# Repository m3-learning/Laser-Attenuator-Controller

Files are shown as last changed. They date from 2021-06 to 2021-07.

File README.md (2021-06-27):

# Laser-Attenuator-Controller

Open source laser attenuator controller

Created by: The M3 Learning Group

All designs and code by: Ryan Forelli

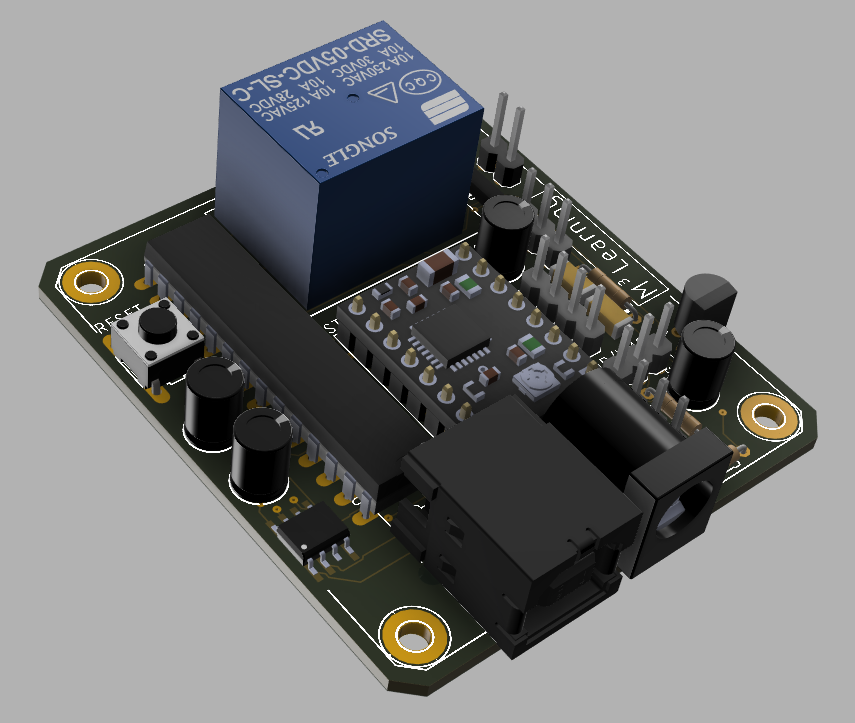
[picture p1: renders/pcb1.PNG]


## Components needed for PCB assembly
-   1x Custom PCB
-   1x A4988 stepper motor drivers
-   1x ATmega328P AVR microcontroller
-   1x Male & female pin header set
-   1x through hole pushbutton
-   1x 16 MHz crystal oscillator
-   2x 22pF ceramic capacitors
-   1x 10uF electrolytic capacitor
-   1x 100uF electrolytic capacitor
-   2x 100nF capacitors
-   3x 10k through-hole resistor
-   1x Assorted solid-core jumper wires
-   1x [Standoffs][0] (optional)
-   1x Custom back plate (optional)
-   1x [USB to TTL Adapter][2]
-   1x PN2222 transistor
-   1x 1N400X series diode
-   1x 5V SRD-05VDC-SL-C relay
-   1x CH330N USB to serial chip (optional if using USB to TTL Adapter)
-   1x 5.5x2.1 DC power port
-   1x USB type B female port

Our open source PCB and firmware can be used to control an attenuator controller to adjust the power output of a laser for applications such as pulsed laser deposition. The program attenuator_control.exe can be used to communicate with the ATmega328p microcontroller to control the attenuator. The LabVIEW and C++ source code is available in the repository.

## Installation Notes
-   Supply PCB with 5V from USB to TTL Adapter.
-   Supply stepper motor controller and relay with 24V.

<!-- ## Usage Instructions
-   Power PLD Controller module
-   Open LabVIEW pldsyscontrol.exe and run Virtual Instrument (VI)
-   Select COM port
-   Home raster motor (does not home to a specific target)
-   Select target and begin use -->

[0]: https://www.amazon.com/Csdtylh-Male-Female-Standoff-Stainless-Assortment/dp/B06Y5TJXY1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
[1]: https://www.amazon.com/gp/product/B074M15FS1/ref=ppx_yo_dt_b_asin_title_o02_s00?ie=UTF8&psc=1
[2]: https://www.amazon.com/DSD-TECH-SH-U09C2-Debugging-Programming/dp/B07TXVRQ7V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

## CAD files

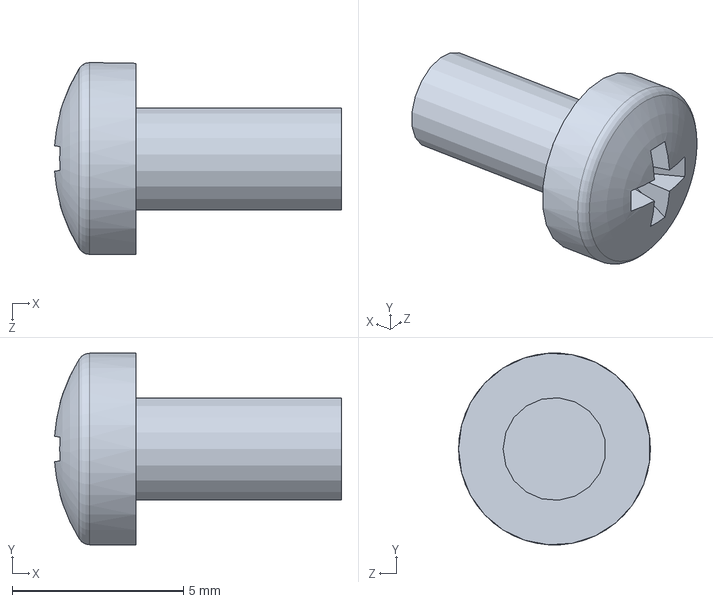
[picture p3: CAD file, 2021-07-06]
3d_models/PCB_shield/Tornillo acero M3x6mm.SLDPRT
8.37 x 5.59 x 5.60 mm

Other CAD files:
3d_models/OldVersions/side plate.0002.ipt
3d_models/PCB_shield/Assembly1.iam
3d_models/PCB_shield/OldVersions/Assembly1.0005.iam
3d_models/PCB_shield/OldVersions/Tornillo acero M3x6mm.0001.ipt
3d_models/PCB_shield/OldVersions/shield.0004.ipt
3d_models/PCB_shield/Tornillo acero M3x6mm.ipt
3d_models/PCB_shield/shield.ipt
3d_models/laser_pcb.ipt
3d_models/side plate.ipt

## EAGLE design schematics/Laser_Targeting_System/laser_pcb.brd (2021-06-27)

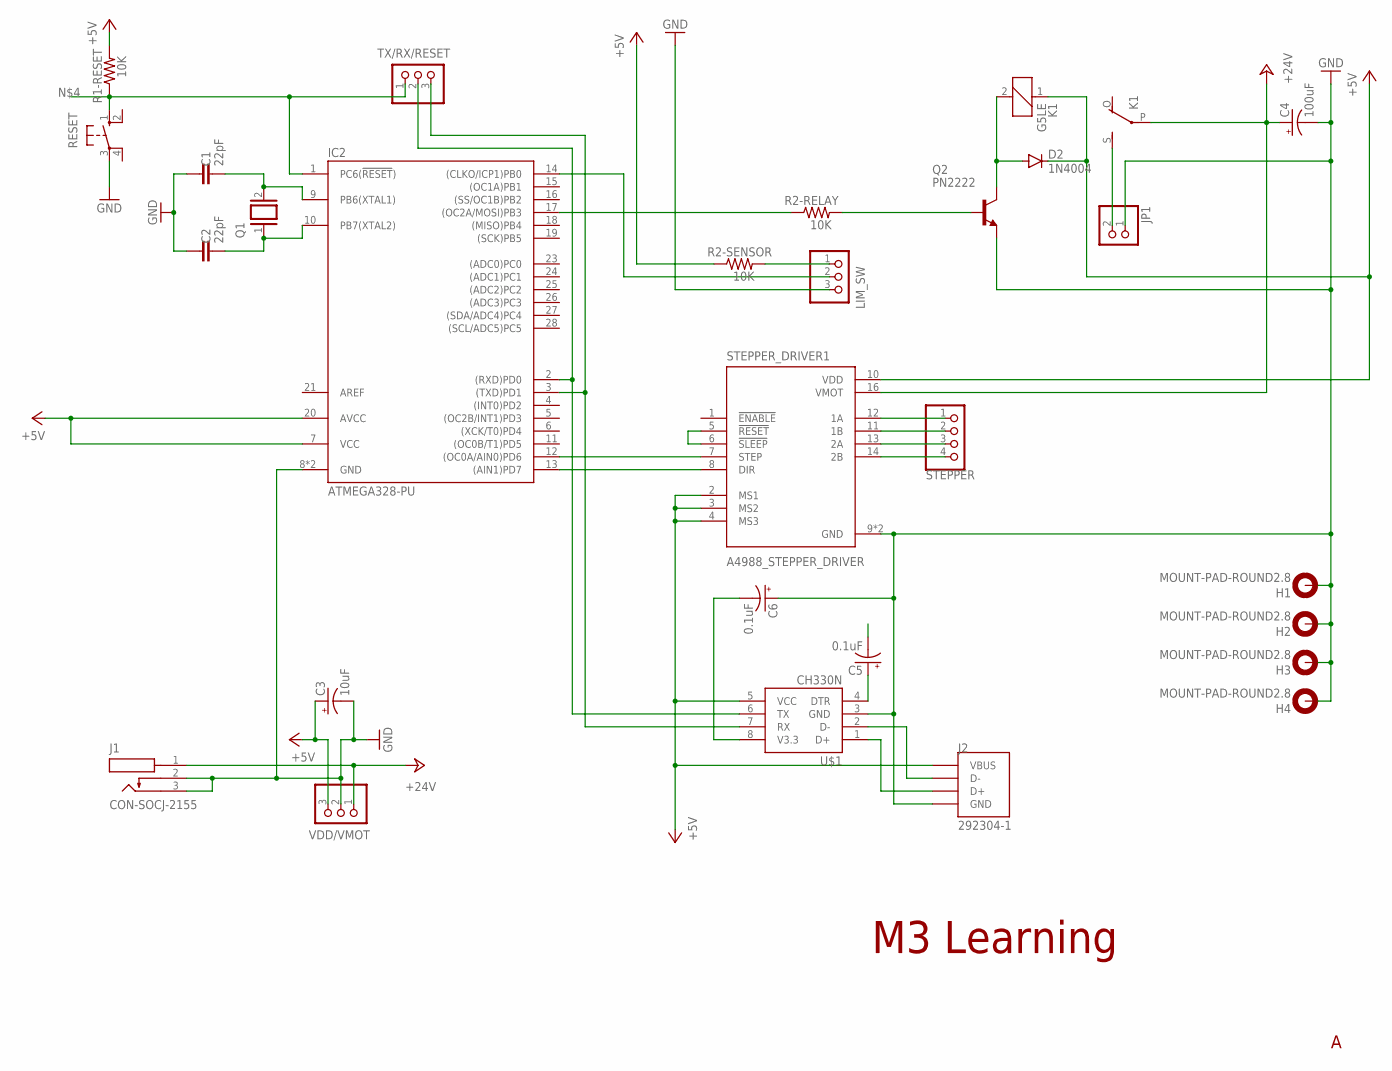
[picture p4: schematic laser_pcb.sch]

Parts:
C1, C2: 22pF; CAP-PTH-2.54
C3: 10uF; CPOL-RADIAL-2.5MM-5MM
C4: 100uF; CPOL-RADIAL-2.5MM-5MM
C5, C6: 0.1uF; CPOL-RADIAL-2.5MM-5MM
D2: 1N4004; DO41-10
H1, H2, H3, H4: MOUNT-PAD-ROUND2.8; 2,8-PAD
IC2: ATMEGA328-PU; DIL28
J1: CON-SOCJ-2155; GRAVITECH_CON-SOCJ-2155
J2: 292304-1; TE_292304-1
JP1: PINHD-1X2; 1X02
K1: G5LE
LIM_SW: PINHD-1X3; 1X03
Q1: XTAL/S; QS
Q2: PN2222; TO92
R1-RESET, R2-RELAY, R2-SENSOR: 10K; 0204/7
RESET: 10-XX; B3F-10XX
STEPPER: PINHD-1X4; 1X04
STEPPER_DRIVER1: A4988_STEPPER_DRIVER; MODULE_A4988_STEPPER_MOTOR_DRIVER_CARRIER
TX/RX/RESET: PINHD-1X3; 1X03
U$1: CH330N; SOIC8
VDD/VMOT: PINHD-1X3; 1X03

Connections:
+5V: C3.1 (+), D2.C, IC2.7 (VCC), IC2.20 (AVCC), J2.1 (VBUS), K1.1, R1-RESET.2, R2-SENSOR.1, STEPPER_DRIVER1.2 (MS1), STEPPER_DRIVER1.3 (MS2), STEPPER_DRIVER1.4 (MS3), STEPPER_DRIVER1.10 (VDD), U$1.5 (VCC), VDD/VMOT.3
+24V: C4.1 (+), J1.1, K1.P, STEPPER_DRIVER1.16 (VMOT), VDD/VMOT.1
GND: C1.1, C2.1, C3.2 (-), C4.2 (-), C6.1 (+), H1.B2,8, H2.B2,8, H3.B2,8, H4.B2,8, IC2.8 (GND), IC2.22 (GND), J1.2, J1.3, J2.4 (GND), JP1.1, LIM_SW.3, Q2.1 (E), RESET.3, STEPPER_DRIVER1.9 (GND), STEPPER_DRIVER1.15 (GND), U$1.3 (GND), VDD/VMOT.2
unnamed: C1.2, IC2.9 (PB6(XTAL1)), Q1.2
unnamed: C2.2, IC2.10 (PB7(XTAL2)), Q1.1
unnamed: C5.2 (-), IC2.1 (PC6(!RESET!)), R1-RESET.1, RESET.1 (S), TX/RX/RESET.1
unnamed: STEPPER_DRIVER1.5 (!RESET), STEPPER_DRIVER1.6 (!SLEEP)
unnamed: IC2.13 ((AIN1)PD7), STEPPER_DRIVER1.8 (DIR)
unnamed: IC2.12 ((OC0A/AIN0)PD6), STEPPER_DRIVER1.7 (STEP)
unnamed: STEPPER.1, STEPPER_DRIVER1.12 (1A)
unnamed: STEPPER.2, STEPPER_DRIVER1.11 (1B)
unnamed: STEPPER.3, STEPPER_DRIVER1.13 (2A)
unnamed: STEPPER.4, STEPPER_DRIVER1.14 (2B)
unnamed: LIM_SW.1, R2-SENSOR.2
unnamed: Q2.2 (B), R2-RELAY.2
unnamed: IC2.14 ((CLKO/ICP1)PB0), LIM_SW.2
unnamed: JP1.2, K1.S
unnamed: D2.A, K1.2, Q2.3 (C)
unnamed: IC2.17 ((OC2A/MOSI)PB3), R2-RELAY.1
unnamed: J2.2 (D-), U$1.2 (D-)
unnamed: J2.3 (D+), U$1.1 (D+)
unnamed: C5.1 (+), U$1.4 (DTR)
unnamed: C6.2 (-), U$1.8 (V3.3)
unnamed: IC2.2 ((RXD)PD0), TX/RX/RESET.2, U$1.6 (TX)
unnamed: IC2.3 ((TXD)PD1), TX/RX/RESET.3, U$1.7 (RX)

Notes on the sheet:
M3 Learning

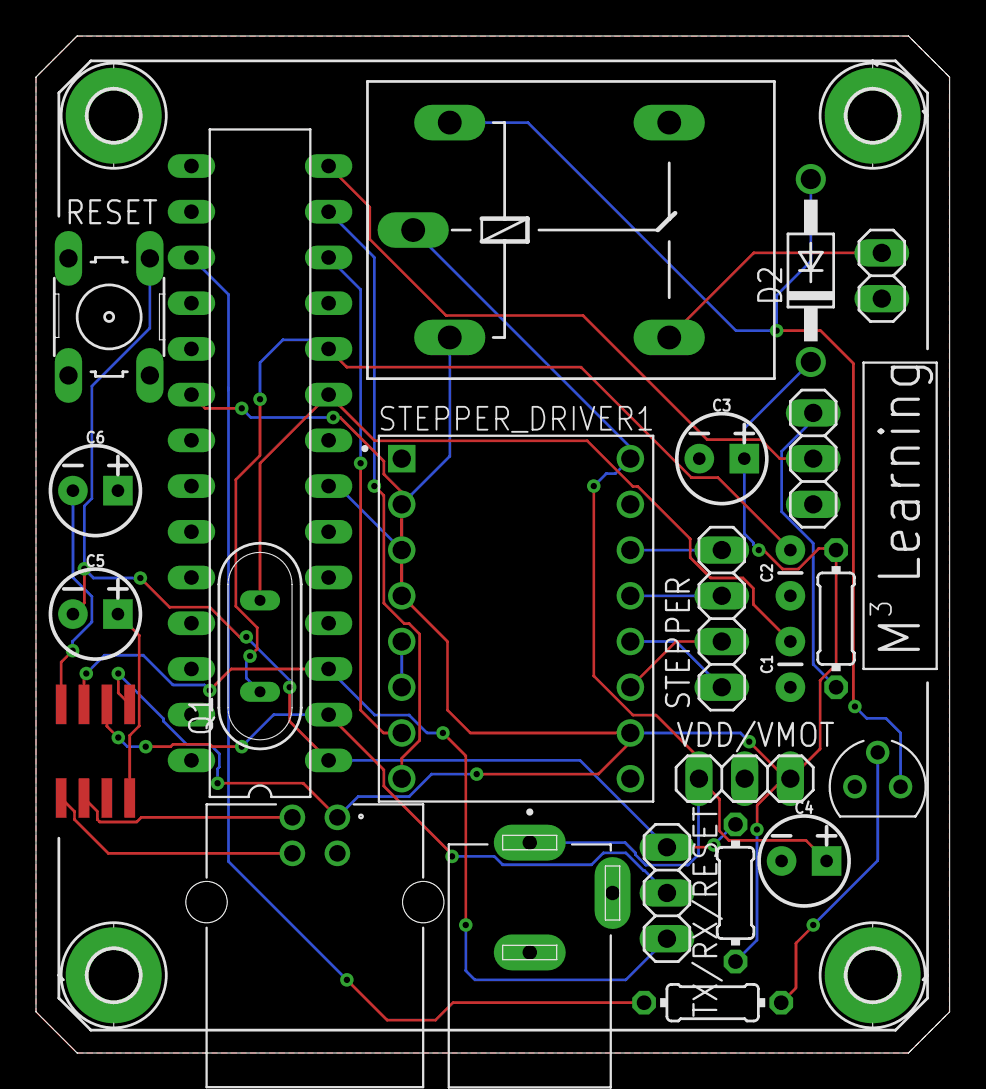
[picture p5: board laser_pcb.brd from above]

Board: 2 copper layers, 50.8 x 56.5 mm, 28 parts (0 on the bottom side), 25 nets.

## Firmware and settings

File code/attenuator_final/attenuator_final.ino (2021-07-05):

#include <Arduino.h>
#include <math.h>

/*
 * By: Ryan Forelli
 * M3 Learning group
 * Current setup has ~3538 steps per degree (with MS 1, 2, and 3 set high)
 * Default speed is 5 deg/sec
*/

unsigned long steps_rotate_per_rev = 1273808;              //Steps required for one revolution
unsigned long max_angle = 90;                              //Maximum allowed angle for attenuator
int steps_per_deg = 3538;                                  //Steps per degree
unsigned long steps_max_angle = max_angle * steps_per_deg; //Steps to maximum angle

float curr_angle = 0;                                      //Current angle
float dest_angle = -1;                                     //Destination angle
float angle_rotate = -1;                                   //Degrees to rotate to reach destination angle
unsigned long steps_rotate;                                //Steps to rotate to reach destination
unsigned long calibration_counter = 0;

char command;                                              //Command from user

unsigned long delay_micros;                                //Delay in microseconds to achieve desired angular velocity

//Macros
#define CW HIGH                                            //Clockwise
#define CCW LOW                                            //Counter Clockwise
#define DIR_PIN 7                                          //Dir pin on A4988
#define STEP_PIN 6                                         //Step pin on A4988
#define LASER_BLOCK 11                                     //Rotary solenoid pin
#define HOME_SWITCH 8                                      //Limit switch pin
#define MIN_SPEED 1                                        //Minimum speed in deg/sec
#define MAX_SPEED 8                                        //Maximum speed in deg/sec
#define STEP                      \
    digitalWrite(STEP_PIN, HIGH); \
    digitalWrite(STEP_PIN, LOW);  \
    delayMicroseconds(delay_micros)
#define setRotationSpeed(new_rotation_speed) ((1 / (double)(steps_per_deg * new_rotation_speed)) * 1000000) //Set rotation speed
#define setDirection(dir) (digitalWrite(DIR_PIN, dir))                                                      //Set direction
#define BLOCK_LASER digitalWrite(LASER_BLOCK, LOW)                                                          //Block laser path
#define CLEAR_LASER digitalWrite(LASER_BLOCK, HIGH)                                                         //Clear laser path

void setup(){
    Serial.begin(9600);

    //Set inputs and outputs
    pinMode(LASER_BLOCK, OUTPUT);
    pinMode(HOME_SWITCH, INPUT);
    pinMode(DIR_PIN, OUTPUT);
    pinMode(STEP_PIN, OUTPUT);
    delay_micros = setRotationSpeed(5);
}

void loop(){
    //Check for available characters to read from serial port
    if (Serial.available() > 0){ Serial.readBytes(&command, 1); }

    switch (command){
        case ',':{ //Rotate to the desired angle
            dest_angle = Serial.parseFloat(SKIP_NONE, ',');
            if ((dest_angle != curr_angle) && (dest_angle <= max_angle) && (dest_angle >= 0)){
                angle_rotate = abs(curr_angle - dest_angle);
                setDirection(((curr_angle - dest_angle) > 0));
                curr_angle = dest_angle;
                //steps_rotate = map(angle_rotate, 0, max_angle, 0, steps_max_angle);
                steps_rotate = (angle_rotate / max_angle) * steps_max_angle;
                Serial.println('\0');
                for(int i=0;i<steps_rotate;i++){
                    STEP;
                }
            }
            break;
        }case '#':{ //Set rotation speed
            int new_speed = Serial.parseFloat(SKIP_NONE, '#');
            delay_micros = (new_speed <= MAX_SPEED && new_speed >= MIN_SPEED) ? setRotationSpeed(new_speed) : delay_micros;
            break;
        }case 'o':{ //Home the attenuator
            setDirection(CW);
            while (1){
                Serial.println('\0');
                if (digitalRead(HOME_SWITCH)){
                    curr_angle = 0;
                    break;
                }
                STEP;
            }
            break;
        }case 'f':{ //Clear laser
            CLEAR_LASER;
            break;
        }case 'g':{ //Block laser
            BLOCK_LASER;
            break;
        }case 'c':{ //Calibrate angle
            //Manually adjust attenuator to desired maximum angle, enter "c" command to the serial monitor and note the number of steps printed and change steps_per_deg and max_angle accordingly. Reupload code.
            setDirection(CW);
            while (1){
                if (digitalRead(HOME_SWITCH)){
                    Serial.println(calibration_counter);
                    calibration_counter = 0;
                    break;
                }
                STEP;
                calibration_counter++;
            }
            break;
        }default:
            break;
    }
    command = '\0';
}

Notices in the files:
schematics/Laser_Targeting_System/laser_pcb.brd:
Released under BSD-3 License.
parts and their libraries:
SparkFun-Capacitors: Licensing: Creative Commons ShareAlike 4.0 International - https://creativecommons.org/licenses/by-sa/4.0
